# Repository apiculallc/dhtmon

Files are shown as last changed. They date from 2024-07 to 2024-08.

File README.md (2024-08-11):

## Objective

To create a small, contained and "offline" temperature / humidity monitoring system for hard-to-reach places like attics, garages, crawlspaces, sheds etc.

## Requirements

- GNU make
- GCC
- [ESP-IDF toolkit](https://docs.espressif.com/projects/esp8266-rtos-sdk/en/latest/)
- Docker

### Hardware / BOM

| Part | Quantity | Price ( approx ) | Link |
|---|---|---|--|
| ESP8266 | 1 | $ 1.20 | https://www.ebay.com/itm/185185809189?var=692941428853 |
| DHT22/AM2302 | 1 | $ 3.33 | https://www.amazon.com/gp/product/B08TGQY64D/ref=ppx_yo_dt_b_search_asin_title?ie=UTF8&th=1 |
| AMS1117 | 1 | $ 0.35 | https://www.amazon.com/gp/product/B08CDMZMDN/ref=ppx_yo_dt_b_search_asin_title?ie=UTF8&psc=1 |
|  Capacitor 10mF | 1 |  $ 0.03  | https://www.amazon.com/gp/product/B087785H1J/ref=ppx_yo_dt_b_search_asin_title?ie=UTF8&psc=1 |
| USB 2.0 Type A Male Socket Connector Jack Port | 1 |  $ 0.11  | https://www.amazon.com/gp/product/B07QY6GJ6M/ref=ppx_yo_dt_b_search_asin_title?ie=UTF8&th=1 |
| Push button 6mm | 1 |  $ 0.07  | https://www.ebay.com/itm/312535619242 |
| SMD Resistor 10kOhm | 4 |  $ 0.03  | https://www.ebay.com/itm/163584740236 |
| PCB | 1 |  $ 2.57  | https://oshpark.com/ |

### Total: ~$8 per board

#### You can also order the board at our blog at https://www.apicula.com/blog/monitoring-temperature-and-humidity-in-unoccupied-zones/

## Build

Clone the repository as `git clone --recurse-submodules -j8 git://github.com/apiculallc/dht.git`

### ESP8266 firmware

- follow the instructions to setup the [ESP-IDF toolchain](https://docs.espressif.com/projects/esp8266-rtos-sdk/en/latest/get-started/index.html#setup-toolchain)
- edit `nvs.csv` file to specify the location and name of the sensor. You can skip this step and configure everything using WiFi setup
  - `wifi_ssid` - name of the access point to connect to
  - `wifi_password` - WiFi password 
  - `app_location` - sensor location ( attic, garage etc )
  - `app_mqtt_url` - the URL to MQTT broker - this is typically the same location as where you will have InfluxDB and the Hub running
- run `make all` to build the flash image
- run `make flash` to flash the partition table
- run `make nvs` to flash the NVS table with the probe settings

### Hub
- change directory to `go`
- run `make` to build the executable for your platform - you'll need to have [Golang](https://go.dev/) installed
- run `make docker` to build a docker image

### Deployment

With use of [Docker Compose](https://docs.docker.com/compose/) everything shall be straightforward:

```bash
docker-compose up -d
```

That should create all the necessary pieces

For step-by-step instructions please read below.

#### Start Mosquitto

Create a config file `mosquitto.conf` with the content:

```
persistence false

log_dest stdout
log_type warning
log_timestamp true
connection_messages true

listener 1883

## Authentication ##
allow_anonymous true

```
 Then run Mosquitto in Docker as:
```bash
docker run --name mosquitto \
 -d --restart=unless-stopped \ 
 -p 1883:1883 \
 -v `pwd`/mosquitto.conf:/mosquitto/config/mosquitto.conf \
eclipse-mosquitto
```
This will expose Mosquitto on port 1883 and allow anonymous access.
#### Start InfluxDB

Run in Docker as:

```bash
docker run -d -p 8086:8086 \
  --name=dhtmon-influx \
  --restart=unless-stopped \
  -v "/opt/data/influxdb-dhtmon:/var/lib/influxdb2" \
  -v "/opt/config/influxdb-dhtmon:/etc/influxdb2" \
  -e DOCKER_INFLUXDB_INIT_MODE=setup \
  -e DOCKER_INFLUXDB_INIT_USERNAME=admin \
  -e DOCKER_INFLUXDB_INIT_PASSWORD=admin123456 \
  -e DOCKER_INFLUXDB_INIT_ORG=home \
  -e DOCKER_INFLUXDB_INIT_BUCKET=dhtmon \
  -e `DOCKER_INFLUXDB_INIT_ADMIN_TOKEN=token123456 \
  influxdb:2.7-alpine
```

This will provision the instance of InfluxDB locally that exposes port 8086 if you need to check on the connection string.

#### Start Hub

In order to test that the Hub works well, you may use the following command ( assuming you have Golang installed ):
```
APP_MQTT_BROKER=mqtt://127.0.0.1:1883 \
INFLUX_DB=http://127.0.0.1:8086 \
INFLUX_TOKEN=token123456 \
go run main.go
```
This will build the project and start the service. Normal output should look like:
```
DB http://127.0.0.1:8086
TOKEN token123456
2024/07/03 10:11:12 started processing topics
```

Now the system is ready to receive data from the sensors.

Alternatively, use Docker container that you built as:

```
docker run --rm \
  -it \
  -e APP_MQTT_BROKER=mqtt://mosquitto:1883 \
  -e INFLUX_DB=http://dhtmon-influx:8086 \
  -e INFLUX_TOKEN=token123456 \
  --link dhtmon-influx \
  --link mosquitto \
  ghcr.io/apiculallc/dhtmon:latest  

DB http://dhtmon-influx:8086
TOKEN token123456
2024/07/04 10:11:12 started processing topics
```

If the Hub is running without any error, you can automate the process with

```bash
docker run --restart=unless-stopped \
  -it \
  -e APP_MQTT_BROKER=mqtt://mosquitto:1883 \
  -e INFLUX_DB=http://dhtmon-influx:8086 \
  -e INFLUX_TOKEN=token123456 \
  --link dhtmon-influx \
  --link mosquitto \
  ghcr.io/apiculallc/dhtmon:latest  
```
This will start the hub in daemon mode.
### Start sensor

Just plug the sensor - it shall connect to the WiFi access point and then start sending data to the topics. 

## Post-installation steps

There is no LCD screens or anything that can be easily observed by a human being, so it is hard to tell whether the system works as expected. The joy of system level programming! So we shall be creative about our means to verify the functionality.

The easiest way to test that everything works as expected is to use an MQTT client and subscribe to the topics. For example, using [`mqtt-shell`](https://github.com/rainu/mqtt-shell):
```bash
mqtt-shell -b mqtt://127.0.0.1:1883
>> sub /home/sensor/#
/home/sensor/attic/temp | 29.3
/home/sensor/attic/humid | 55.9
/home/sensor/garage/temp | 27.1
/home/sensor/garage/humid | 56.1
```

This indicates that sensors actually transmits data.

To verify that we actually receive something in the database ( InfluxDB ) we need to connect to the DB and run a few queries. As we have the installation that exposes ports 8086 - we can simply open [http://127.0.0.1:8086](http://127.0.0.1:8086) and use login  `admin` and password `admin123456` to peek into the storage.  Choose `Buckets` and select `dhtmon`:
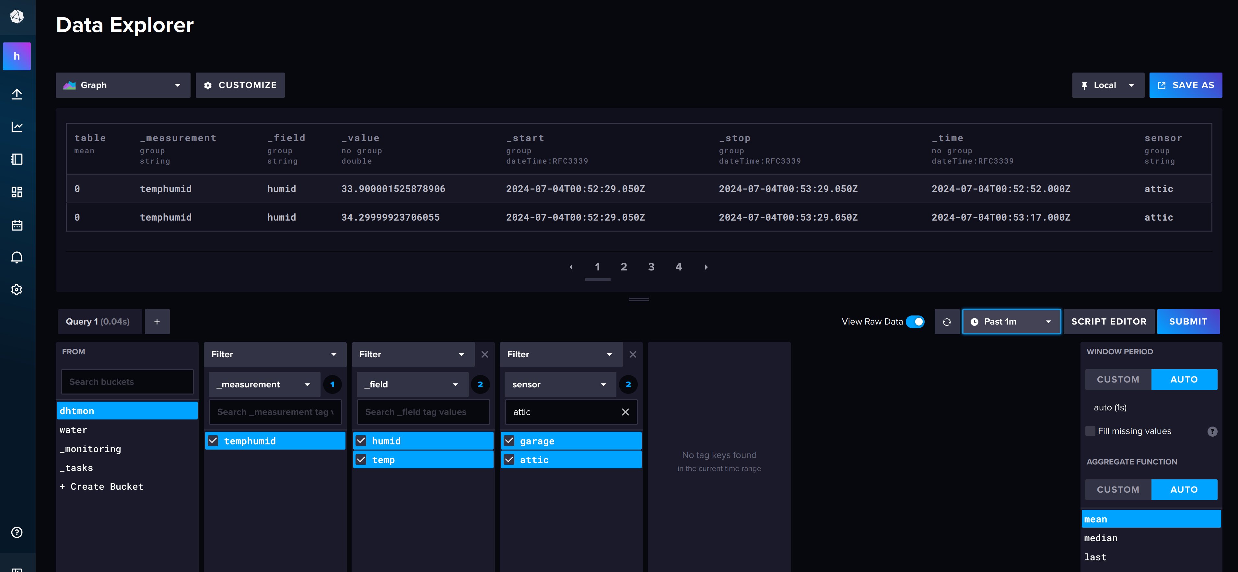
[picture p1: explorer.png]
explore


From here, you may want to configure Grafana.

#### [Grafana](https://grafana.com/)

This is fairly sophisticated and powerful tool for monitoring and alerting in DevOps world. We're going to use it to render the charts and get the most recent data from the set of probes that we setup.

###### Installation

Pull the docker image and link it to a container that runs InfluxDB.

```bash
docker run --restart=unless-stopped \
	-e GF_SECURITY_ADMIN_USER=admin \
	-e GF_SECURITY_ADMIN_PASSWORD=admin123 \
	--link influxdb \
	-p 3000:3000 \
	-v ./grafana/provisioning/:/etc/grafana/provisioning/ \
	-v ./grafana/dashboards/:/var/lib/grafana/dashboards/ \
	grafana/grafana:10.0.10
```

This will populate the default data source with the InfluxDB and then create a dashboard that shall look like following ( if you have some data in there from the sensors ).

To "prime" some data and verify that this part works fine, you can use the following command:

```bash
cat <<EOF | mqtt-shell -b mqtt://127.0.0.1:1883
pub /home/sensor/garage/temp 32.1
pub /home/sensor/garage/humid 55.0
pub /home/sensor/attic/humid 35.0
pub /home/sensor/attic/temp 40.0
pub /home/sensor/crawlspace/temp 27.0
pub /home/sensor/crawlspace/humid 65.0
EOF
Successfully connected to mqtt broker.
```

The result can look like:

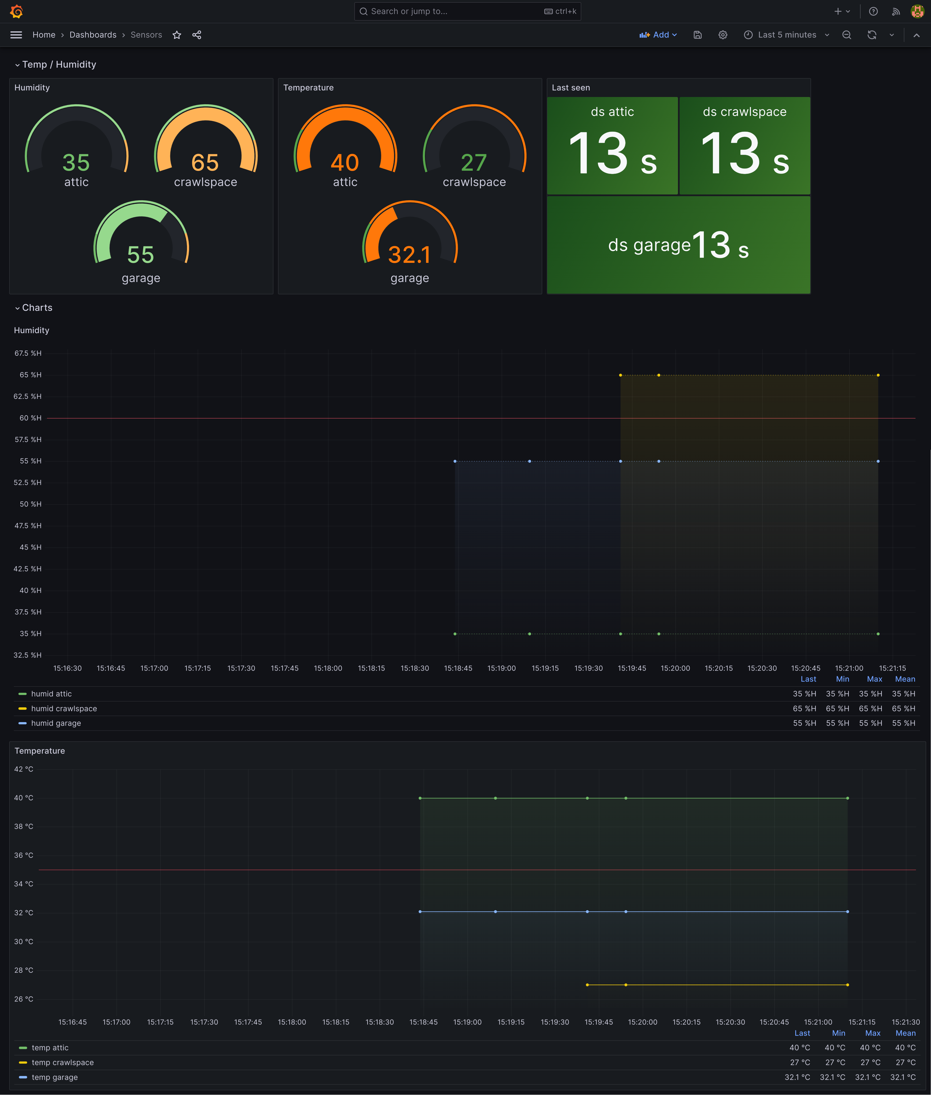
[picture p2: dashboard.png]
Dashboard

After you run that for some time, the result will be much more interesting:

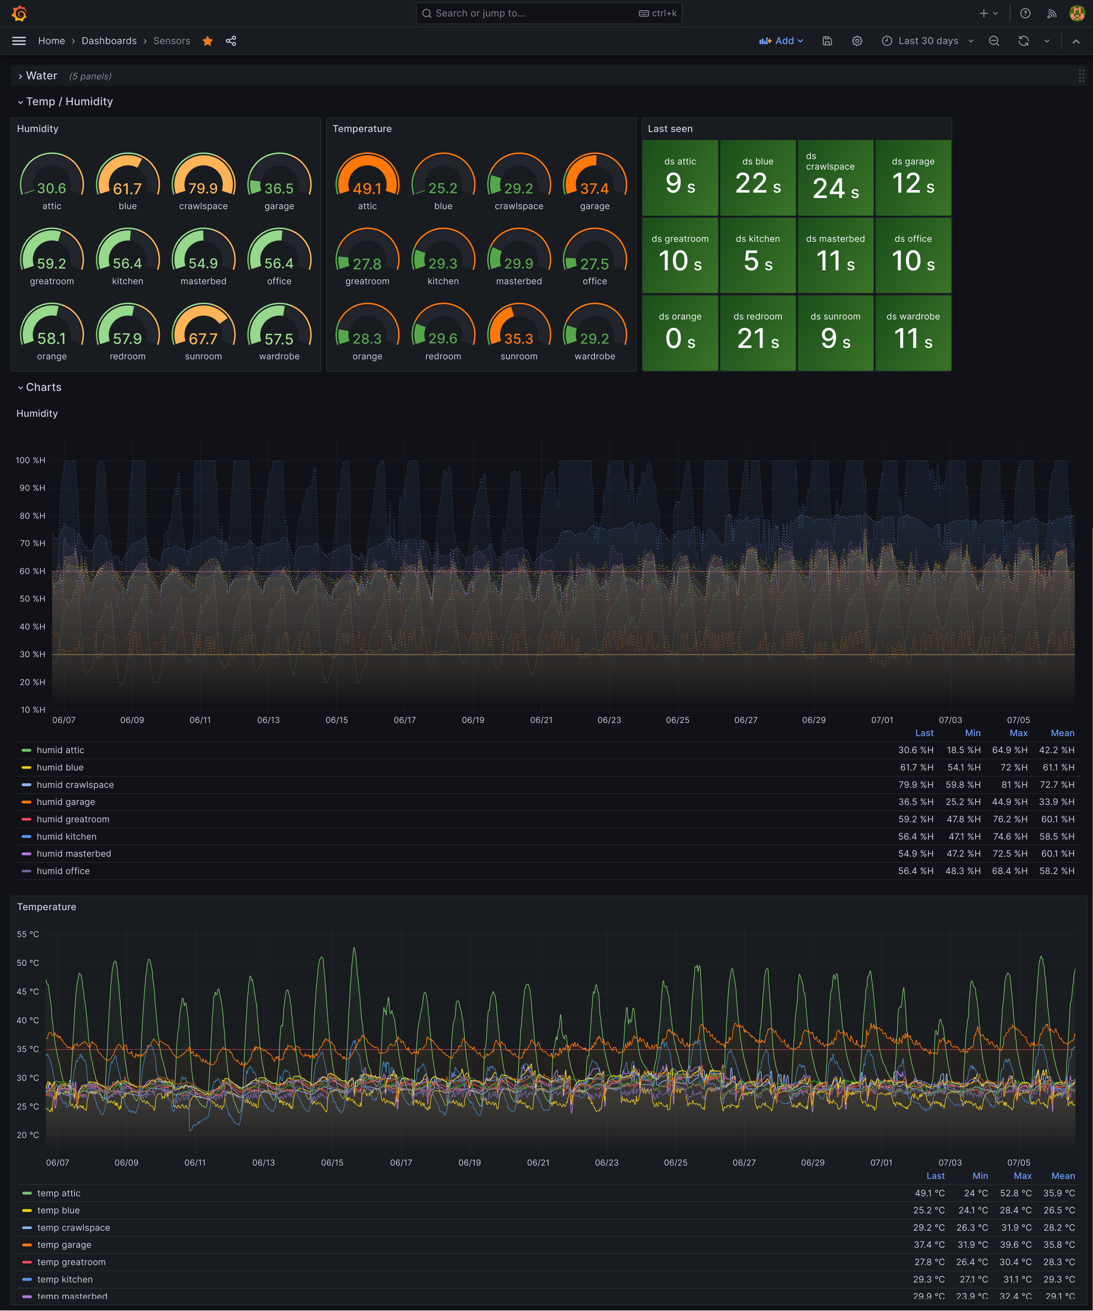
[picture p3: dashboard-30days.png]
Dashboard 30 days


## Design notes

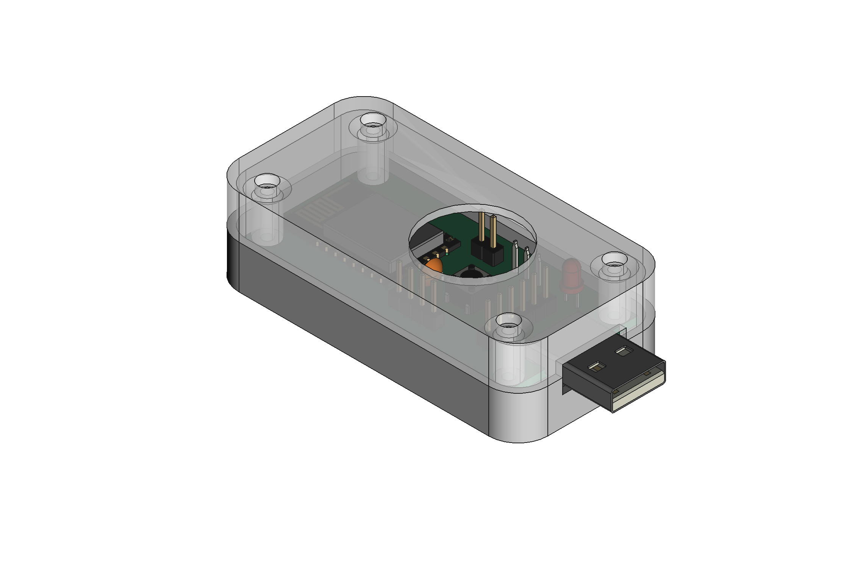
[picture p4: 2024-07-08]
freecad/3D model.png

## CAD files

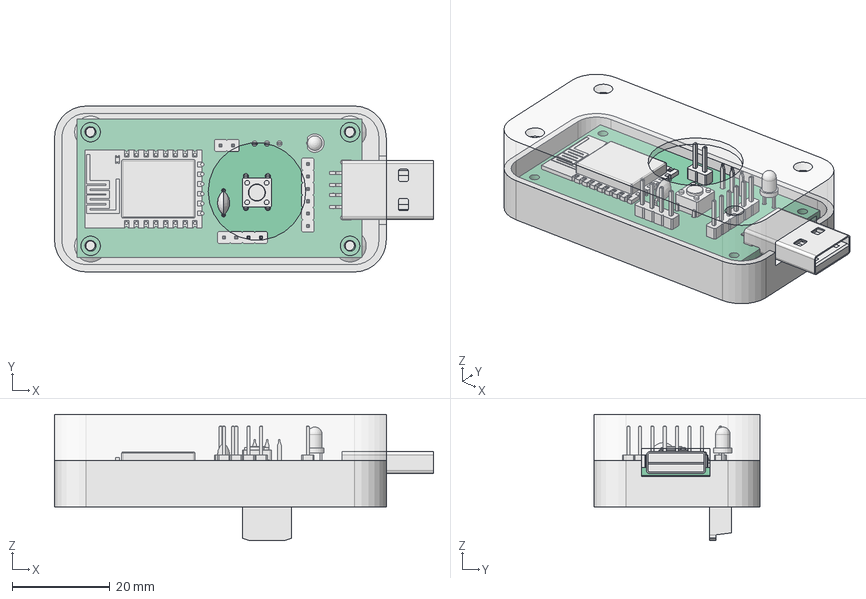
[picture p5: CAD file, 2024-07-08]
freecad/dhtmon.FCStd
77.7 x 34.0 x 25.9 mm
Pcb_858a
ESP_12E001_cp
ESP_12E001_cp001
ESP_12E001_cp002
ESP_12E001_cp003
ESP_12E001_cp004
ESP_12E001_cp005
ESP_12E001_cp006
ESP_12E001_cp007
ESP_12E001_cp008
ESP_12E001_cp009
ESP_12E001_cp010
ESP_12E001_cp011
ESP_12E001_cp012
ESP_12E001_cp013
ESP_12E001_cp014
ESP_12E001_cp015
ESP_12E001_cp016
ESP_12E001_cp017
ESP_12E001_cp018
ESP_12E001_cp019
ESP_12E001_cp020
ESP_12E001_cp021
ESP_12E001_cp022
ESP_12E001_cp023
ESP_12E001_cp024
ESP_12E001_cp025
ESP_12E001_cp026
ESP_12E001_cp027
ESP_12E001_cp028
ESP_12E001_cp029
ESP_12E001_cp030
ESP_12E001_cp031
ESP_12E001_cp032
ESP_12E001_cp033
ESP_12E001_cp034
ESP_12E001_cp035
ESP_12E001_cp036
ESP_12E001_cp037
ESP_12E001_cp038
ESP_12E001_cp039
ESP_12E001_cp040
ESP_12E001_cp041
ESP_12E001_cp042
ESP_12E001_cp043
ESP_12E001_cp044
ESP_12E001_cp045
ESP_12E001_cp046
ESP_12E001_cp047
SW1_SW_PUSH_6mm_e90dab117c7"
JP1_PinHeader_1x02_P254mm_Vertical_5338887fbbb"
USB_A_CNCTech_1001-011-01101_Horizontal
USB_A_CNCTech_1001-011-01101_Horizontal001
USB_A_CNCTech_1001-011-01101_Horizontal002
USB_A_CNCTech_1001-011-01101_Horizontal003
USB_A_CNCTech_1001-011-01101_Horizontal004
USB_A_CNCTech_1001-011-01101_Horizontal005
USB_A_CNCTech_1001-011-01101_Horizontal006
USB_A_CNCTech_1001-011-01101_Horizontal007
USB_A_CNCTech_1001-011-01101_Horizontal008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

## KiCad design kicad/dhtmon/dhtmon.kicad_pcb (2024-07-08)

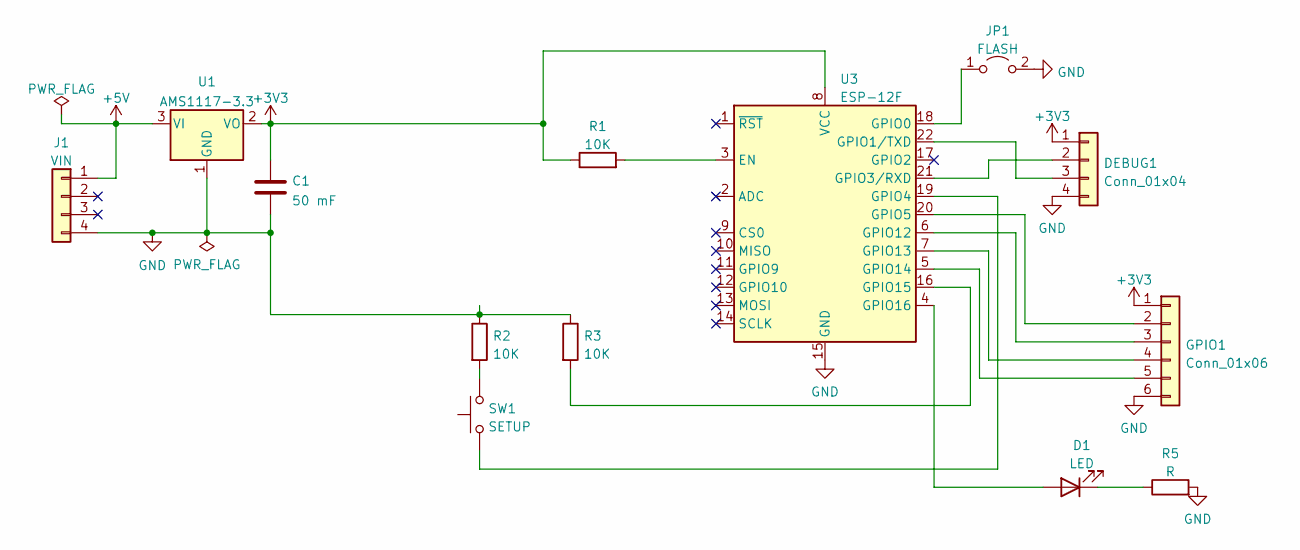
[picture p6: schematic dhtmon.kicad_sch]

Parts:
C1: 50 mF; C_Disc_D5.0mm_W2.5mm_P5.00mm
D1: LED; LED_D3.0mm
DEBUG1: Conn_01x04; PinHeader_1x04_P2.54mm_Vertical
GPIO1: Conn_01x06; PinHeader_1x06_P2.54mm_Vertical
J1: VIN; USB_A_CNCTech_1001-011-01101_Horizontal
JP1: FLASH; PinHeader_1x02_P2.54mm_Vertical
R1, R2, R3: 10K; R_0805_2012Metric
R5: R; R_0805_2012Metric
SW1: SETUP; SW_PUSH_6mm
U1: AMS1117-3.3; TO-262-3_Vertical
U3: ESP-12F; ESP-12E

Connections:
+3V3: C1.1, DEBUG1.1, GPIO1.1, R1.1, U1.2 (VO), U3.8 (VCC)
+5V: J1.1, U1.3 (VI)
GND: C1.2, DEBUG1.4, GPIO1.6, J1.4, JP1.2 (B), R2.1, R3.1, R5.2, U1.1 (GND), U3.15 (GND)
unnamed: D1.2 (A), U3.4 (GPIO16)
unnamed: D1.1 (K), R5.1
unnamed: DEBUG1.2, U3.21 (GPIO3/RXD)
unnamed: DEBUG1.3, U3.22 (GPIO1/TXD)
unnamed: GPIO1.2, U3.20 (GPIO5)
unnamed: GPIO1.3, U3.6 (GPIO12)
unnamed: GPIO1.4, U3.7 (GPIO13)
unnamed: GPIO1.5, U3.5 (GPIO14)
unnamed: JP1.1 (A), U3.18 (GPIO0)
unnamed: R2.2, SW1.2
unnamed: R1.2, U3.3 (EN)
unnamed: SW1.1, U3.19 (GPIO4)
unnamed: R3.2, U3.16 (GPIO15)

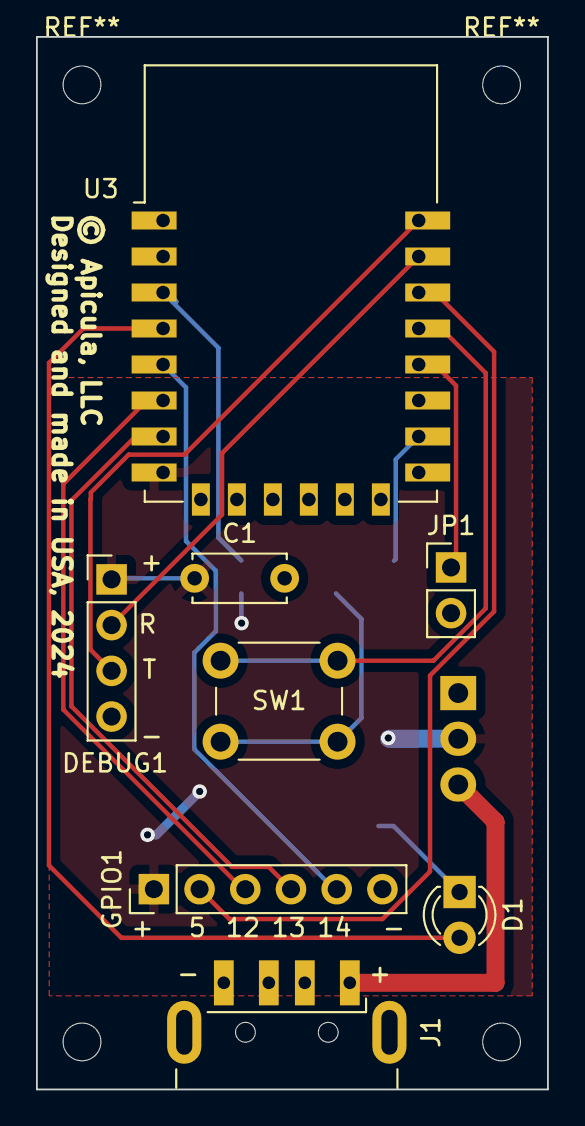
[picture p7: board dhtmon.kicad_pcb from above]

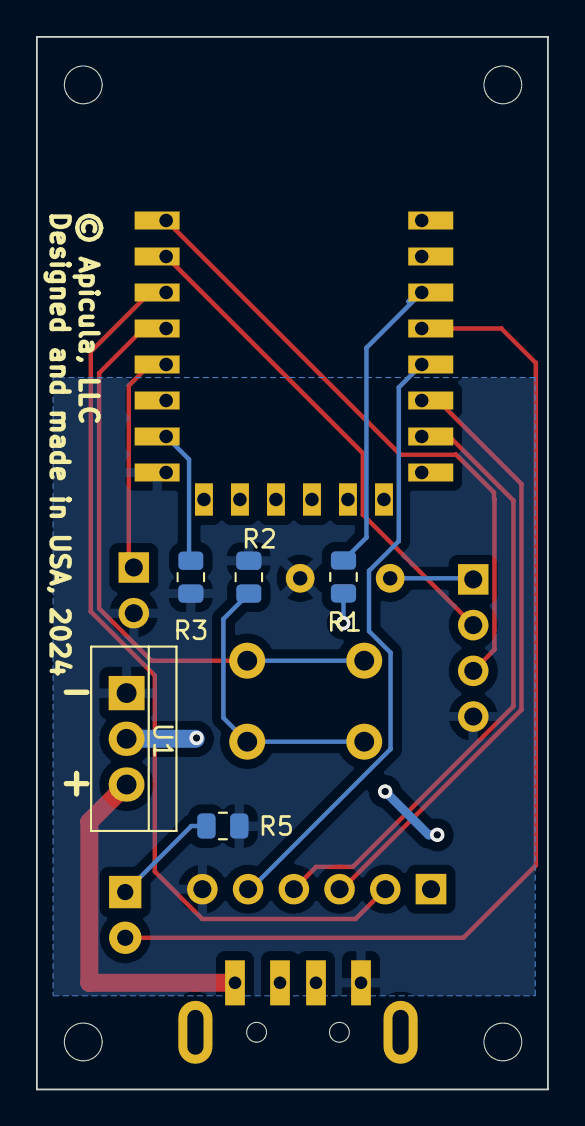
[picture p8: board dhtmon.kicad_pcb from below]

Board: 2 copper layers, 28.4 x 58.5 mm, 15 parts (5 on the bottom side), 16 nets.

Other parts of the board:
REF1, REF2: MountingHole_2.1mm

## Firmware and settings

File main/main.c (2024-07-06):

#include <sys/cdefs.h>
#include <stdio.h>
#include <freertos/FreeRTOS.h>
#include <freertos/task.h>
#include <dht.h>
#include "lwip/err.h"
#include "esp_event.h"
#include "esp_wifi.h"
#include "esp_log.h"
#include "event_groups.h"
#include <stdbool.h>
#include <mqtt_client.h>
#include <nvs_flash.h>
#include <esp_timer.h>
#include <esp_task_wdt.h>
#include "driver/gpio.h"
#include "accesspoint.h"
#include "flash_config.h"

#define WAIT_CONNECT (5000)
#define TAG "DHT_MONITOR"
#define SEND_RETRIES (5)
#define SEND_RETRY_INTERVAL_MS (5000)
#define REPORT_INTERVAL_MS (SEND_RETRIES * SEND_RETRY_INTERVAL_MS + 100)
#define WIFI_CONNECTED_BIT     BIT0
#define MAX_SENSOR_READ_TRIES 3

struct ConfigData app_config;

static const dht_sensor_type_t sensor_type = DHT_TYPE_AM2301;
//static const dht_sensor_type_t sensor_type = DHT_TYPE_DHT11;
static const gpio_num_t dht_sensor_arr[] = {GPIO_NUM_4, GPIO_NUM_5};
static const gpio_num_t dht_btn_arr[] = {GPIO_NUM_5, GPIO_NUM_4};
static gpio_num_t dht_sensor, dht_btn;
const char *endpoint;
static EventGroupHandle_t wifi_event_group;
struct esp_mqtt_client *mqtt_client;

static char *temp; // temperature
static char *humid; // humidity

static void unified_event_handler(void *arg, esp_event_base_t event_base,
                                  int32_t event_id, void *event_data) {
    if (event_base == WIFI_EVENT) {
        ESP_LOGD(TAG, "WIFI_EVENT: %d", event_id);
        if (event_id == WIFI_EVENT_STA_DISCONNECTED) {
            // restart if the connection is dropped
            ESP_LOGE(TAG, "can't connect to wifi");
            esp_restart();
        }
    } else if (event_base == IP_EVENT) {
        ESP_LOGD(TAG, "IP_EVENT: %d", event_id);
        if (event_id == IP_EVENT_STA_GOT_IP) {
            ip_event_got_ip_t *event = (ip_event_got_ip_t *) event_data;
            ESP_LOGI(TAG, "got ip: %s", ip4addr_ntoa((const ip4_addr_t *) &event->ip_info.ip));
            xEventGroupSetBits(wifi_event_group, WIFI_CONNECTED_BIT);
        }
    }
}

static bool connect_wifi() {
    if (!tcpip_adapter_is_netif_up(TCPIP_ADAPTER_IF_STA)) {
        ESP_LOGD(TAG, "starting TCP/IP adapter");
        ESP_ERROR_CHECK(tcpip_adapter_up(TCPIP_ADAPTER_IF_STA));
        ESP_LOGD(TAG, "TCP/IP adapter started");
    }
    tcpip_adapter_dhcp_status_t dhcp_status;
    if (tcpip_adapter_dhcpc_get_status(TCPIP_ADAPTER_IF_STA, &dhcp_status) == ERR_OK) {
        if (dhcp_status != TCPIP_ADAPTER_DHCP_STARTED) {
            ESP_LOGD(TAG, "starting DHCP client");
            ESP_ERROR_CHECK(tcpip_adapter_dhcpc_start(TCPIP_ADAPTER_IF_STA));
            ESP_LOGD(TAG, "DHCP client started");
        } else {
            ESP_LOGE(TAG, "DHCP status %d", dhcp_status);
        }
    }

    ESP_LOGI(TAG, "entering station mode...");

    if (strlen((char *) app_config.wifi_config.sta.password)) {
        app_config.wifi_config.sta.threshold.authmode = WIFI_AUTH_WPA2_PSK;
    }

    ESP_ERROR_CHECK(esp_wifi_set_config(WIFI_IF_STA, &app_config.wifi_config));
    ESP_ERROR_CHECK(esp_wifi_connect());

    ESP_LOGI(TAG, "waiting for wifi connection");

    /* Waiting until either the connection is established (WIFI_CONNECTED_BIT) or connection failed for the maximum
     * number of re-tries (WIFI_FAIL_BIT). The bits are set by event_handler() (see above) */
    EventBits_t bits = xEventGroupWaitBits(wifi_event_group,
                                           WIFI_CONNECTED_BIT,
                                           pdTRUE,
                                           pdFALSE,
                                           pdMS_TO_TICKS(WAIT_CONNECT));
    /* xEventGroupWaitBits() returns the bits before the call returned, hence we can test which event actually
     * happened. */
    if (bits & WIFI_CONNECTED_BIT) {
        ESP_LOGI(TAG, "connected to ap SSID:%s", app_config.wifi_config.sta.ssid);
    } else {
        ESP_LOGE(TAG, "NEITHER WIFI_CONNECTED_BIT NOR WIFI_FAIL_BIT ARE SET");
    }
    return bits & WIFI_CONNECTED_BIT;
}

void report_temp_humidity(TimerHandle_t pxTimer) {
    ESP_LOGD(TAG, "TIMER TASK");
    int16_t temperature = 0;
    int16_t humidity = 0;

    // DHT sensors that come mounted on a PCB generally have
    // pull-up resistors on the data pin.  It is recommended
    // to provide an external pull-up resistor otherwise...

    int8_t sensor_read_attempts = 0;
    if (dht_read_data(sensor_type, dht_sensor, &humidity, &temperature) == ESP_OK) {
        ESP_LOGI(TAG, "Humidity: %d%% Temp: %dC", humidity / 10, temperature / 10);
    } else {
        ESP_LOGE(TAG, "Could not read data from sensor");
        sensor_read_attempts++;
        if (sensor_read_attempts > MAX_SENSOR_READ_TRIES) {
            esp_restart();
        }
        return;
    }

    int try = 0;
    for (; try < SEND_RETRIES; try++) {
        ESP_LOGI(TAG, "SENDING DATA ATTEMPT %d", try);
#define bufSz 10
        static char buf[bufSz];
        int sz = snprintf(buf, bufSz, "%d.%d", temperature / 10, temperature % 10);
        ESP_LOGI(TAG, "sending temp: '%s'", buf);
        int ret = esp_mqtt_client_publish(mqtt_client, temp, buf,
                                          sz, 1, 0);
        if (ret < 0) {
            ESP_LOGE(TAG, "can't send temperature to %s => %d", temp, ret);
            vTaskDelay(SEND_RETRY_INTERVAL_MS);
            continue;
        }
        sz = sprintf(buf, "%d.%d", humidity / 10, humidity % 10);
        ESP_LOGI(TAG, "sending humidity: '%s'", buf);
        ret = esp_mqtt_client_publish(mqtt_client, humid, buf,
                                      sz, 1, 0);
        if (ret < 0) {
            ESP_LOGE(TAG, "can't send temperature to %s => %d", temp, ret);
            vTaskDelay(SEND_RETRY_INTERVAL_MS);
            continue;
        }
        try = SEND_RETRIES + 1;
    }
    // check if the retry counter was exhausted because of the consequent errors
    if (try == SEND_RETRIES) {
        ESP_LOGE(TAG, "FAILED TO SEND DATA, REBOOT");
        esp_restart();
    } else {
        gpio_set_level(BUILTIN_LED, 0);
        vTaskDelay(pdMS_TO_TICKS(250));
        gpio_set_level(BUILTIN_LED, 1);
    }
    esp_task_wdt_reset();
}

void read_dht_mainloop() {
    ESP_LOGI(TAG, "init tcp/ip stack");
    tcpip_adapter_init();
    ESP_LOGI(TAG, "create default loop");
    ESP_ERROR_CHECK(esp_event_loop_create_default());
    // init watchdog
    ESP_ERROR_CHECK(esp_task_wdt_init());
    ESP_LOGI(TAG, "init wifi");
    wifi_init_config_t cfg = WIFI_INIT_CONFIG_DEFAULT();
    ESP_ERROR_CHECK(esp_wifi_init(&cfg));
    ESP_ERROR_CHECK(esp_wifi_set_mode(WIFI_MODE_STA));
    ESP_ERROR_CHECK(esp_wifi_start());
    ESP_LOGI(TAG, "create custom event handler");
    wifi_event_group = xEventGroupCreate();
    ESP_ERROR_CHECK(esp_event_handler_register(WIFI_EVENT, WIFI_EVENT_STA_DISCONNECTED, &unified_event_handler, NULL));
    ESP_ERROR_CHECK(esp_event_handler_register(IP_EVENT, IP_EVENT_STA_GOT_IP, &unified_event_handler, NULL));
    if (!connect_wifi()) {
        esp_restart();
    }
    esp_mqtt_client_config_t mqtt_cfg = {
            .uri = app_config.network.mqtt_uri,
    };
    mqtt_client = esp_mqtt_client_init(&mqtt_cfg);
    ESP_ERROR_CHECK(esp_mqtt_client_start(mqtt_client));

    ESP_LOGI(TAG, "init WDT");
    ESP_ERROR_CHECK(esp_task_wdt_init());
    TimerHandle_t timerChannel = xTimerCreate("DHT_READ",
                                              (pdMS_TO_TICKS(REPORT_INTERVAL_MS)),
                                              pdTRUE,
                                              (void *) 1,
                                              report_temp_humidity
    );
    assert(timerChannel);
    assert(xTimerStart(timerChannel, 0) == pdPASS);

}

_Noreturn void display_error() {
    for (;;) {
        gpio_set_level(BUILTIN_LED, 0);
        sleep(1);
        gpio_set_level(BUILTIN_LED, 1);
        sleep(1);
    }
}

static xQueueHandle gpio_evt_queue = NULL;
static int64_t latest_btn_event;
const int short_press = 1000;
static bool armed = false;
static int64_t evt;

/**
 * The GPIO event handler that will trigger and send the event to the queue once falling edge is detected and current
 * GPIO status is "low"
 */
void btnPressHandler(void *arg) {
    if (gpio_get_level(dht_btn) == 0) {
        evt = esp_timer_get_time();
        xQueueSendFromISR(gpio_evt_queue, &evt, NULL);
    }
}

/*
 * The task that is being triggered "async" to confirm that UUID was set.
 */
static void uuid_set_blinker(void *arg) {
    for (int i = 0; i <= 5; i++) {
        gpio_set_level(BUILTIN_LED, 0);
        sleep(1);
        gpio_set_level(BUILTIN_LED, 1);
        sleep(1);
    }
    armed = false;
}

/**
 * The event handler for GPIO.
 */
static void gpio_event_task(void *arg) {
    int64_t evt_time;
    for (;;) {
        if (xQueueReceive(gpio_evt_queue, &evt_time, pdMS_TO_TICKS(short_press * 2))) {
            ESP_LOGD(TAG, "button pressed");
            if ((evt_time - latest_btn_event) / 1000 > short_press) {
                latest_btn_event = evt_time;
                if (!armed) {
                    armed = true;
                    continue;
                }
                xTaskCreate(uuid_set_blinker, "uuid blinker set", 1024, NULL, 10, NULL);
            }
        }
    }
}


void app_main() {
    esp_err_t ret = nvs_flash_init();
    if (ret == ESP_ERR_NVS_NO_FREE_PAGES || ret == ESP_ERR_NVS_NEW_VERSION_FOUND) {
        display_error();
    }
    ESP_ERROR_CHECK(ret);
    // Reads the various configuration parameters into the application config from NVS.
    ESP_LOGI(TAG, "Reading configuration");
    ret = read_app_config(&app_config);
    if (ret != ESP_OK) {
        ESP_LOGE(TAG, "Can't read config: %s", esp_err_to_name(ret));
        display_error();
    }

    temp = malloc(sizeof(CONFIG_APP_MQTT_TOPIC"/temp") + strlen(app_config.location) - 1);
    humid = malloc(sizeof(CONFIG_APP_MQTT_TOPIC"/humid") + strlen(app_config.location) - 1);

    sprintf(temp, CONFIG_APP_MQTT_TOPIC"/temp", app_config.location);
    sprintf(humid, CONFIG_APP_MQTT_TOPIC"/humid", app_config.location);

    ESP_LOGI(TAG, "temp: '%s';\nhumid: '%s'", temp, humid);

    gpio_config_t conf = {
            .pin_bit_mask = (1 << BUILTIN_LED),
            .mode = GPIO_MODE_DEF_OUTPUT,
            .pull_up_en = GPIO_PULLUP_DISABLE,
            .pull_down_en = GPIO_PULLDOWN_ENABLE,
            .intr_type = GPIO_INTR_DISABLE
    };
    ESP_ERROR_CHECK(gpio_config(&conf));
    gpio_set_level(BUILTIN_LED, 1);
    bool gpioFound = false;
    for (int sensorIdx = 0; !gpioFound && sensorIdx < sizeof(dht_sensor_arr) / sizeof(gpio_num_t); sensorIdx++) {
        dht_sensor = dht_sensor_arr[sensorIdx];
        dht_btn = dht_btn_arr[sensorIdx];
        ESP_LOGI(TAG, "reading GPIO %d", dht_sensor);
        ESP_ERROR_CHECK(gpio_set_pull_mode(dht_sensor, GPIO_PULLUP_ONLY))
        int16_t humidity, temperature;
        for (int try = 0; try < 3 && !gpioFound; try++) {
            if (dht_read_data(sensor_type, dht_sensor, &humidity, &temperature) == ESP_OK) {
                ESP_LOGI(TAG, "found DHT GPIO %d", dht_sensor);
                ESP_LOGI(TAG, "found BTN GPIO %d", dht_btn);
                gpioFound = true;
                ESP_LOGI(TAG, "Humidity: %d%% Temp: %dC", humidity / 10, temperature / 10);
                gpio_set_level(BUILTIN_LED, 0);
                sleep(1);
                gpio_set_level(BUILTIN_LED, 1);
            } else {
                ESP_LOGW(TAG, "can't read GPIO %d, sleeping", dht_sensor);
                sleep(2);
            }
        }
    }
    // if we can't read data - no point of connecting to a wifi.

    if (!gpioFound) {
        ESP_LOGE(TAG, "can't read DHT");
        display_error();
    }

    gpio_set_pull_mode(dht_btn, GPIO_PULLUP_ONLY);
    if (gpio_get_level(dht_btn) == 0) {
        if (startAp(&app_config) != 0) {
            display_error();
        }
        gpio_set_level(BUILTIN_LED, 0);
    } else {
        read_dht_mainloop();
    }

    gpio_set_intr_type(dht_sensor, GPIO_INTR_LOW_LEVEL);
    // create a queue to process GPIO tasks
    gpio_evt_queue = xQueueCreate(5, sizeof(uint32_t));
    // poll events from the gpio_evt_queue and run processing outside of the IRQ event loop.
    xTaskCreate(gpio_event_task, "btn event handler", 2048, NULL, 10, NULL);

    // Register IRQ for the control button press events
    ESP_ERROR_CHECK(gpio_install_isr_service(0));

    gpio_isr_handler_add(dht_sensor, &btnPressHandler, NULL);
}

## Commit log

2024-07-06 MQTT publishing of the sensor data.
2024-07-06 Restart on Wifi failures.
    Fix float processing issue / snprintf.
    [main.c]
2024-07-06 Added web config and AP mode for easy setup.
    [nvs.csv]
2024-07-06 Assign GPIO for button
    Can be altered between GPIO4/GPIO5 depending on wiring schema.
2024-07-08 Added 3D models and KiCAD schematics.
    [dhtmon.FCStd, dhtmon.kicad_pcb, dhtmon.kicad_sch]
2024-07-08 Added 3D model for the case.
2024-08-11 Added BOM and link to the blog.

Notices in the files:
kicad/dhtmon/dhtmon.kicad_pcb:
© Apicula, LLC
